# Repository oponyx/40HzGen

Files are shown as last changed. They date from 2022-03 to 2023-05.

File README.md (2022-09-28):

:warning: **warning:This device will flash/strobe the light!  Don't use it next to individuals with epilepsy!** :warning:

:warning: **The research has not been tested and has not been proven to work on humans! Use it at your own risk!** :warning:

#
# 40HzGen
An advanced [ESP8266](https://en.wikipedia.org/wiki/ESP8266) based device used to drive a 40Hz (programmable) flashing led light for brain stimulation and non invasive Alzheimer Gamma Light Therapy.

https://www.webmd.com/brain/what-to-know-about-gamma-brain-waves

http://news.mit.edu/2016/visual-stimulation-treatment-alzheimer-1207

https://picower.mit.edu/innovations-inventions/genus

### Features:
  * Complete configuration and control through web pages
  * Programmable Light On-Time, flickering Frequence and Brightness 
  * WIFI Station and AP mode
#

# Prototype board

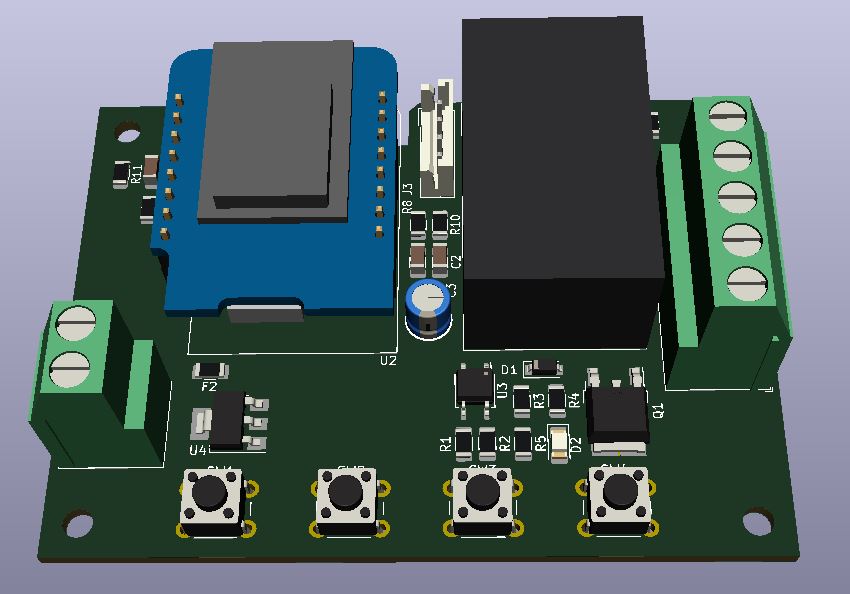
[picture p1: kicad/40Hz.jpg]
Prototype PCB


### Hardware notes:
 * Board designed to be fitted with 'Wemos D1 mini' or 'ESP12F' modules
 * Optional OLED SS1306 Display 
 * Power to logic from AC main (populating PS1 with a HLK-PM01 module) or external 5V
 * External Input for Light Power 
 * ESP01 version (in progress)

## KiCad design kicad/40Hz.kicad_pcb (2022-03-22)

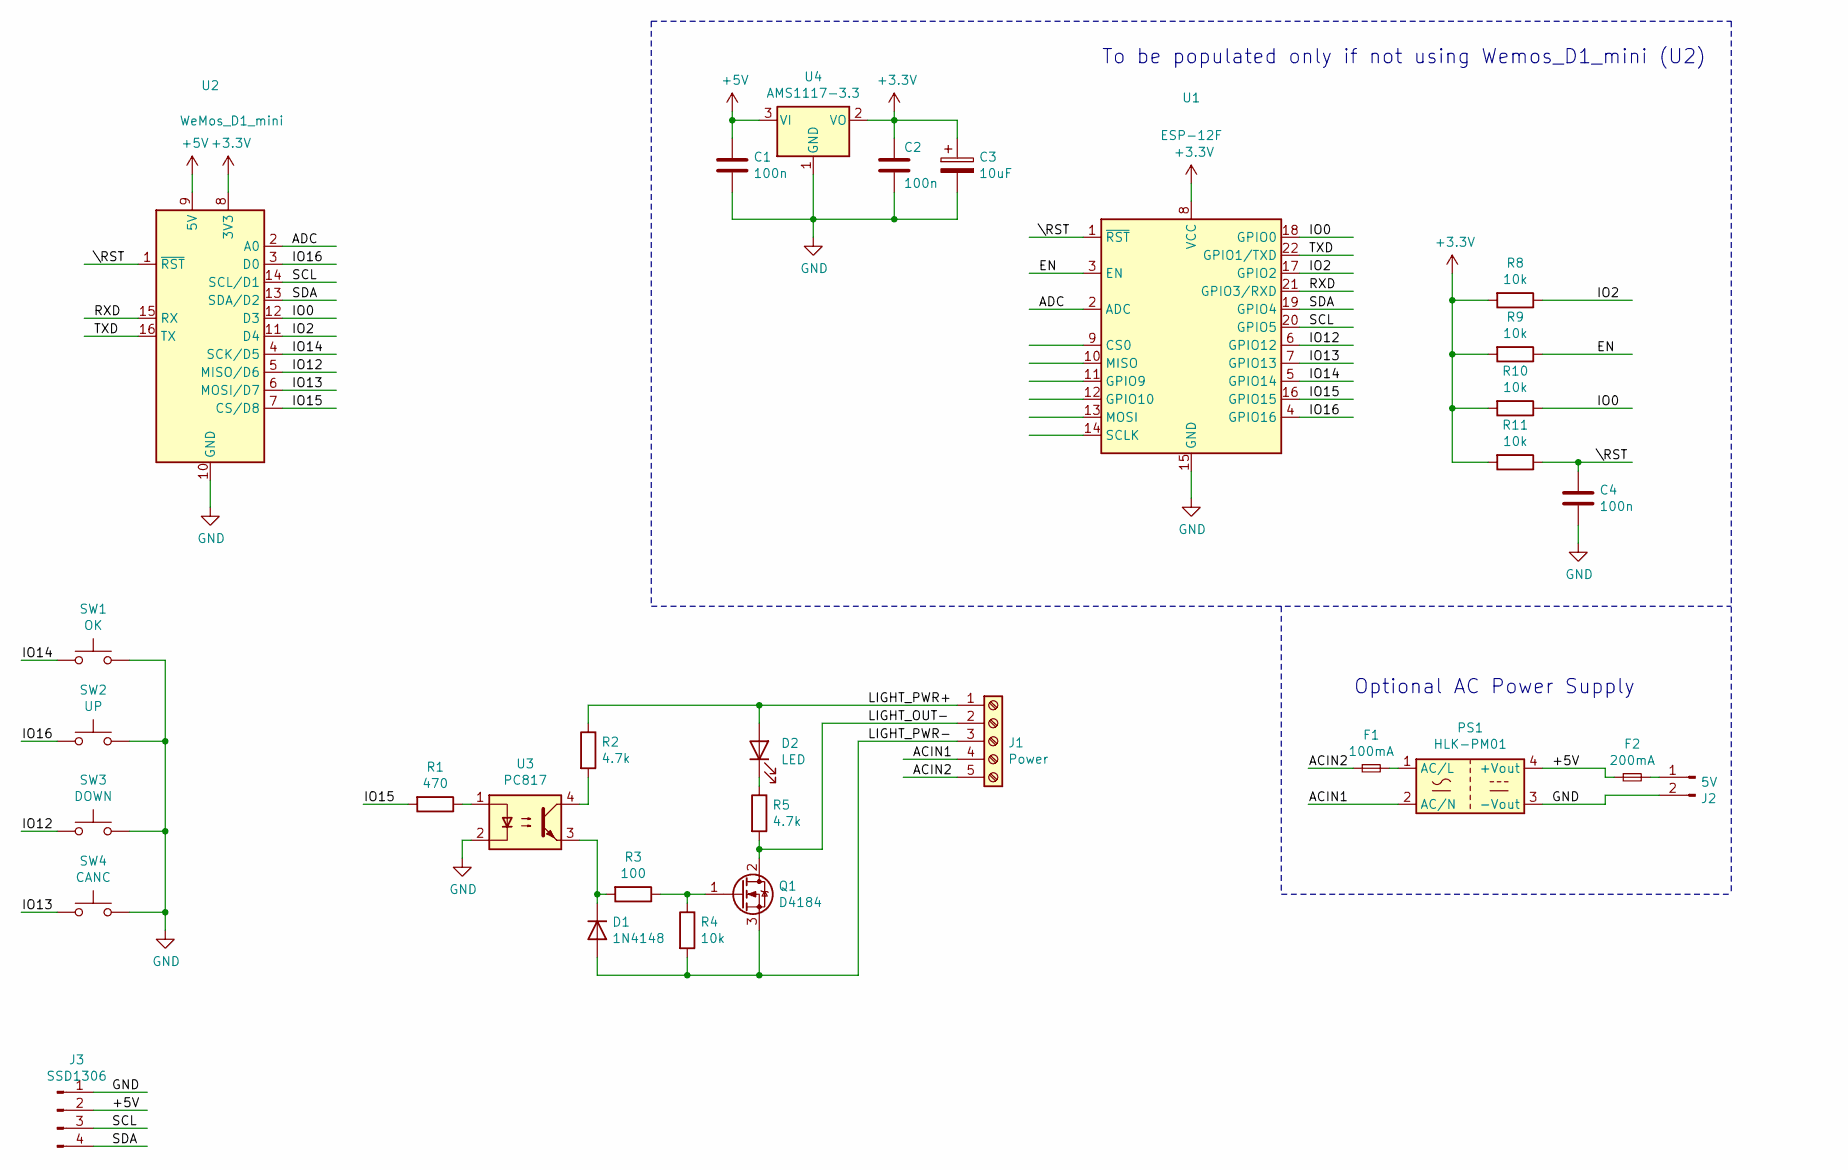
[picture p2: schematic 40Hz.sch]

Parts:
C1, C2, C4: 100n; C_1206_3216Metric
C3: 10uF; CP_Radial_D5.0mm_P2.50mm
D1: 1N4148; D_SOD-123
D2: LED; LED_1206_3216Metric_Pad1.42x1.75mm_HandSolder
F1: 100mA; Fuse_1206_3216Metric
F2: 200mA; Fuse_1206_3216Metric
J1: Power; TerminalBlock_Phoenix_MKDS-3-5-5.08_1x05_P5.08mm_Horizontal
J2: 5V; TerminalBlock_Phoenix_MKDS-3-2-5.08_1x02_P5.08mm_Horizontal
J3: SSD1306; JST_EH_B4B-EH-A_1x04_P2.50mm_Vertical
PS1: HLK-PM01; Converter_ACDC_HiLink_HLK-PMxx
Q1: D4184; TO-252-2
R1: 470; R_1206_3216Metric
R2, R5: 4.7k; R_1206_3216Metric
R3: 100; R_1206_3216Metric
R4, R8, R9, R10, R11: 10k; R_1206_3216Metric
SW1: OK; SW_PUSH_6mm_H5mm
SW2: UP; SW_PUSH_6mm_H5mm
SW3: DOWN; SW_PUSH_6mm_H5mm
SW4: CANC; SW_PUSH_6mm_H5mm
U1: ESP-12F; ESP-12E
U2: WeMos_D1_mini; WEMOS_D1_mini_light
U3: PC817; SOP-4_3.8x4.1mm_P2.54mm
U4: AMS1117-3.3; SOT-223-3_TabPin2

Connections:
+3V3: C2.1, C3.1, R8.2, R9.2, R10.2, R11.2, U1.8 (VCC), U2.8 (3V3), U4.2 (VO)
+5V: C1.1, F2.1, J3.2, PS1.4 (+Vout), U2.9 (5V), U4.3 (VI)
/ACIN1: J1.4, PS1.2 (AC/N)
/ACIN2: F1.1, J1.5
/ADC: U1.2 (ADC), U2.2 (A0)
/EN: R9.1, U1.3 (EN)
/IO0: R10.1, U1.18 (GPIO0), U2.12 (D3)
/IO2: R8.1, U1.17 (GPIO2), U2.11 (D4)
/IO12: SW3.1, U1.6 (GPIO12), U2.5 (MISO/D6)
/IO13: SW4.1, U1.7 (GPIO13), U2.6 (MOSI/D7)
/IO14: SW1.1, U1.5 (GPIO14), U2.4 (SCK/D5)
/IO15: R1.2, U1.16 (GPIO15), U2.7 (CS/D8)
/IO16: SW2.1, U1.4 (GPIO16), U2.3 (D0)
/LIGHT_OUT-: J1.2, Q1.2 (D), R5.2
/LIGHT_PWR+: D2.2 (A), J1.1, R2.1
/LIGHT_PWR-: D1.2 (A), J1.3, Q1.3 (S), R4.2
/RXD: U1.21 (GPIO3/RXD), U2.15 (RX)
/SCL: J3.3, U1.20 (GPIO5), U2.14 (SCL/D1)
/SDA: J3.4, U1.19 (GPIO4), U2.13 (SDA/D2)
/TXD: U1.22 (GPIO1/TXD), U2.16 (TX)
/\RST: C4.1, R11.1, U1.1 (~RST), U2.1 (~RST)
GND: C1.2, C2.2, C3.2, C4.2, J2.2, J3.1, PS1.3 (-Vout), SW1.2, SW2.2, SW3.2, SW4.2, U1.15 (GND), U2.10 (GND), U3.2, U4.1 (GND)
unnamed: D1.1 (K), R3.2, U3.3
unnamed: D2.1 (K), R5.1
unnamed: F1.2, PS1.1 (AC/L)
unnamed: F2.2, J2.1
unnamed: Q1.1 (G), R3.1, R4.1
unnamed: R1.1, U3.1
unnamed: R2.2, U3.4

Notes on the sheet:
To be populated only if not using Wemos_D1_mini (U2)
Optional AC Power Supply

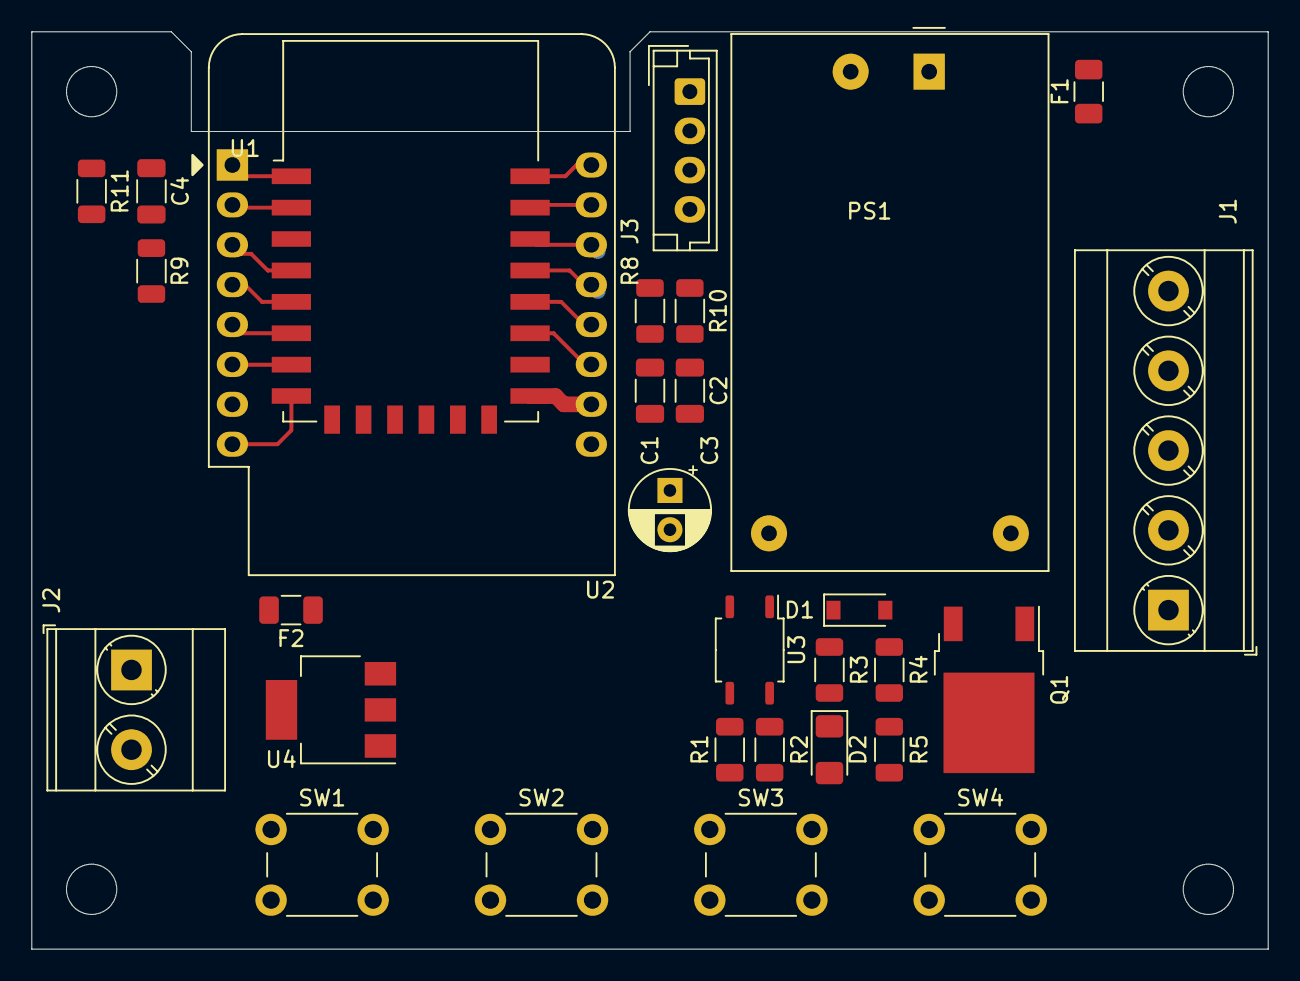
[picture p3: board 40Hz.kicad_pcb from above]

Board: 2 copper layers, 78.7 x 58.4 mm, 30 parts (0 on the bottom side), 29 nets.

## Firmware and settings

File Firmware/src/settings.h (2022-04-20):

/*
settings.h

MIT License

Copyright (c) 2022 Pagliarulo Onofrio (oponyx@hotmail.it)

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
THE SOFTWARE IS PROVIDED "AS IS", WITHOUT WARRANTY OF ANY KIND, EXPRESS OR
IMPLIED, INCLUDING BUT NOT LIMITED TO THE WARRANTIES OF MERCHANTABILITY,
FITNESS FOR A PARTICULAR PURPOSE AND NONINFRINGEMENT. IN NO EVENT SHALL THE
AUTHORS OR COPYRIGHT HOLDERS BE LIABLE FOR ANY CLAIM, DAMAGES OR OTHER
LIABILITY, WHETHER IN AN ACTION OF CONTRACT, TORT OR OTHERWISE, ARISING FROM,
OUT OF OR IN CONNECTION WITH THE SOFTWARE OR THE USE OR OTHER DEALINGS IN THE
SOFTWARE.
*/
#ifndef _SETTINGS_H_
#define _SETTINGS_H_

#include <stdint.h>
#include <EEPROM.h>
#include <CRC16.h>

#define SETTINGS_VERSION          0x00000010

#ifdef WIFI_DEFAULT_ENABLED
#define WIFI_DEFAULT_ENABLED WIFI_DEFAULT_ENABLED_OVERRIDE
#else 
#define WIFI_DEFAULT_ENABLED         true
#endif

#ifdef WIFI_DEFAULT_SSID_OVERRIDE
#define WIFI_DEFAULT_SSID WIFI_DEFAULT_SSID_OVERRIDE
#else 
#define WIFI_DEFAULT_SSID         "SSID_NONE"
#endif

#ifdef WIFI_DEFAULT_PASSW_OVERRIDE
#define WIFI_DEFAULT_PASSW WIFI_DEFAULT_PASSW_OVERRIDE
#else
#define WIFI_DEFAULT_PASSW        "12345678"
#endif

#ifdef AUTOSTART_OVERRIDE
#define AUTOSTART AUTOSTART_OVERRIDE
#else
#define AUTOSTART false
#endif

#define AP_DEFAULT_SSID           "40Hz_Gen"
#define AP_DEFAULT_PASSW          "12345678"
#ifndef DEFAULT_LIGHT_FREQ
#define DEFAULT_LIGHT_FREQ        40
#endif
#ifndef DEFAULT_ON_TIME
#define DEFAULT_ON_TIME           60
#endif
#define DEFAULT_BRIGHTNESS        100
#define DEFAULT_PWM_FREQ          1000
#define DEFAULT_AUDIO_ENABLED     true
#define DEFAULT_LIGHT_ENABLED     true






uint8_t SettingsRead();
uint8_t restoreDefaultSettings();
uint8_t SettingsWrite();
uint16_t SettingsCRC();

typedef union {
  uint8_t data;
  struct {
  uint8_t type            : 3;
  uint8_t autostart       : 1;
  uint8_t spare1          : 1;
  uint8_t wifiEnabled     : 1;
  uint8_t audioEnabled    : 1;
  uint8_t lightEnabled    : 1;
  };
} flags;

typedef struct {
  uint16_t      crc;                        // crc settings
  uint32_t      version;                    // Settings version  
  flags         settingFlags;               // Flag Byte Stored in Settings
  char          wifi_ssid[24];              // Wifi SSID Stored in Setting
  char          wifi_psw[24];               // Wifi Password Stored in Setting
  char          ap_ssid[16];                // Access Poin Mode SSID name Stored in Setting
  char          ap_psw[16];                 // Access Poin Mode Password Stored in Setting
  uint8_t       light_freq;                 // Gamma Frequence Stored in Setting
  uint8_t       on_time;                    // OnTime Stored in Setting
  uint8_t       brightness;                 // light brightness 10-100%
  uint32_t      pwm_freq;                   // light pwm frequence
} TSettings;

extern TSettings Settings;


#endif

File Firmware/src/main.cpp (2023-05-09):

/*
main.cpp - 40HzGen main file

MIT License

Copyright (c) 2022 Pagliarulo Onofrio (oponyx@hotmail.it)

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
THE SOFTWARE IS PROVIDED "AS IS", WITHOUT WARRANTY OF ANY KIND, EXPRESS OR
IMPLIED, INCLUDING BUT NOT LIMITED TO THE WARRANTIES OF MERCHANTABILITY,
FITNESS FOR A PARTICULAR PURPOSE AND NONINFRINGEMENT. IN NO EVENT SHALL THE
AUTHORS OR COPYRIGHT HOLDERS BE LIABLE FOR ANY CLAIM, DAMAGES OR OTHER
LIABILITY, WHETHER IN AN ACTION OF CONTRACT, TORT OR OTHERWISE, ARISING FROM,
OUT OF OR IN CONNECTION WITH THE SOFTWARE OR THE USE OR OTHER DEALINGS IN THE
SOFTWARE.
*/

#include <Arduino.h>

#include "hw_config.h"
#include "config_override.h"
#include "globals.h"
#include "config.h"
#include "log.h"
#include "settings.h"
#include "wifi_func.h"
#include "web_serv.h"
#include "functions.h"
#include "error_codes.h"
#include "button.hpp"
#include "graphic.h"
#include "version.h"



bool bDisplayUpdated;         // 'Display is updated' flag
bool bOutputStatus;
u_long lastSwitch;
bool bButtonChanged=false;
uint16_t LightPWMDutyVal = 0;
deviceStatus_t Status;

Button okButton(OK_BUTTON_PIN, INPUT_PULLUP, OK_BUTT_ACTIVE_LVL);
#ifdef CANCEL_BUTTON_PIN
Button cancelButton(CANCEL_BUTTON_PIN, INPUT_PULLUP, CANCEL_BUTT_ACTIVE_LVL);
#endif
#ifdef UP_BUTTON_PIN
Button upButton(UP_BUTTON_PIN, INPUT_PULLUP, UP_BUTT_ACTIVE_LVL);
#endif
#ifdef DOWN_BUTTON_PIN
Button downButton(DOWN_BUTTON_PIN, INPUT_PULLUP, DOWN_BUTT_ACTIVE_LVL);
#endif


void IRAM_ATTR buttonChangedISR(){
 bButtonChanged = true;
}

/**
 * @brief Main setup function
 * 
 */
void setup() {

#ifdef ESP32
  Serial.begin(115200);
#else
  Serial.begin(74880);
#endif
  // load settings
  D_PRINT(false, "\n");
  D_PRINTLN(true, "Serial ok");
  
  // restore default settings if okButton pressed at powerup
  D_PRINT(true, "Checking if button pressed for reset to default settings...");
  ulong ms = millis();
  while (millis() < (ms + 1000)){
    if(digitalRead(OK_BUTTON_PIN) == OK_BUTT_ACTIVE_LVL){
      D_PRINT(true, "Restoring default settings...");
      restoreDefaultSettings();
    }
  }
  D_PRINTLN(false, "Done");

  D_PRINT(true, "Loading Settings..");
  uint8_t result = SettingsRead();
  if( result != 0 ){
    switch ( result )
    {
    case ERROR_SETTINGS_CRC:
        D_PRINT(true, "\nError: Bad CRC on settings datas\nResoring default settings.\n");
        restoreDefaultSettings();
      break;
    
    default:
      break;
    }
  }else{
    D_PRINT(false, "Ok\n");
  }

#ifdef LCD_POPULATED
  D_PRINT(true, "Setting up Display...");
  if(display_init()){
    D_PRINTLN(false, "FAIL!");
  }
  D_PRINTLN(false, "Ok.");

  dispLogoPage();
  delay(1000);

  display.clearDisplay();
  display.setTextSize(1);             // Normal 1:1 pixel scale
  display.setTextColor(WHITE);        // Draw white text
  display.setCursor(0,0);             // Start at top-left corner

  
  display.printf("Setting up WIFI...");
#endif

  if(Settings.settingFlags.wifiEnabled){
    D_PRINT(true, "Setting up WIFI...");
    if(!wifi_setup()){
      D_PRINTLN(false, "WIFI connection KO!");   
    }
    else{
      D_PRINTLN(false, "OK!");
      D_PRINTLN(true, "WIFI connection Successful");
      D_PRINTLN(true, "WIFI IP Address is:%s", WiFi.localIP().toString().c_str() );
    }
  }
  else{
    D_PRINTLN(true, "Wifi is NOT enabled!!");
  }

  D_PRINT(true, "Setting up AP...");
  if(!AP_setup()){  
    D_PRINTLN(false, "KO!!");
  }
  else{
    D_PRINTLN(false, "OK!");
    D_PRINTLN(true, "AP IP address = %s" ,  WiFi.softAPIP().toString().c_str());
#ifdef LCD_POPULATED
    display.println(WiFi.softAPIP());
#endif
  }

  D_PRINT(true, "Starting web server...");
  if (web_serv_setup() == NO_ERRORS) {
    D_PRINTLN(false, "OK!");
  }else{
    D_PRINTLN(true, "<<<<<<<<<<<<< ERROR!");
  }
  setupIO();
  // test output
#ifdef AUDIO_OUT_PIN
#ifdef ESP32 
  ledcWrite(LIGHT_PWM_CH, (LIGHT_OUT_ACTIVE_LVL)  ? pow(2,LIGHT_PWM_RES_BITS) -1 : 0);
  ledcWriteTone(AUDIO_PWM_CH,1000);
#else
  tone(AUDIO_OUT_PIN,TONE_FREQ);
  //digitalWrite(LIGHT_OUT_PIN,LIGHT_OUT_ACTIVE_LVL); 
#endif
#endif
#ifdef LCD_POPULATED
  dispInfoPage();
#endif
  delay(1000);
#ifdef LCD_POPULATED
  dispReadyPage();
#endif
// test output end
#ifdef ESP32
  ledcWrite(LIGHT_PWM_CH, (LIGHT_OUT_ACTIVE_LVL)  ? 0 : pow(2,LIGHT_PWM_RES_BITS)-1);
  ledcWriteTone(AUDIO_PWM_CH,0);
#else
  digitalWrite(LIGHT_OUT_PIN,!LIGHT_OUT_ACTIVE_LVL); 
  noTone(AUDIO_OUT_PIN);
#endif
  D_PRINTLN(true, "WIFI SSID:%s", Settings.wifi_ssid);
  D_PRINTLN(true, "WIFI PWD:%s", Settings.wifi_psw);
  D_PRINTLN(true, "AP SSID:%s", Settings.ap_ssid);
  D_PRINTLN(true, "AP PWD:%s", Settings.ap_psw);
  D_PRINTLN(true, "Light Freq:%u", Settings.light_freq);
  D_PRINTLN(true, "On time:%u", Settings.on_time);
  D_PRINTLN(true, "Brightness:%u", Settings.brightness);
  D_PRINTLN(true, "PWM Freq:%u", Settings.pwm_freq);
  D_PRINTLN(true, "Autostart:%s", (Settings.settingFlags.autostart == true ) ? "ON" : "OFF");
  D_PRINTLN(true, "lightEnabled:%s", (Settings.settingFlags.lightEnabled == true ) ? "ON" : "OFF");
  D_PRINTLN(true, "audioEnabled:%s", (Settings.settingFlags.audioEnabled == true ) ? "ON" : "OFF");

  attachInterrupt(digitalPinToInterrupt(OK_BUTTON_PIN), buttonChangedISR, CHANGE);

  if(Settings.settingFlags.autostart){
    Command = CMD_START;
  }  
  /// tests
  //check_flash();
  //D_PRINTLN(true, "Size of indexp:%d\n", sizeof(index_page));
  //test();
  //testButtonHandle();
  //system_phy_set_powerup_option(0);  // 3 to reset RF CALIBRATION
}



/**
 * @brief Main Loop
 * 
 */
void loop() {
  if (bButtonChanged) {
    //bButtonChanged = false;
    okButton.handle();// only button handling always checked, other buttons only when not working
  }
  handleCommands();
  if((millis()-mills_2)>499){
    mills_2=millis();
    bHalfSecond=!bHalfSecond;
  }
  //flash status led
#ifdef STATUS_LED
  digitalWrite(STATUS_LED, (bHalfSecond == true) ? STATUS_LED_ACTIVE_LVL : !STATUS_LED_ACTIVE_LVL );   
#endif

  if( Status == deviceStatus_t::STATUS_WORKING ){
    // light switch
    u_long now = micros();
    u_long diff = now - lastSwitch;
    
    if( diff >= semiPeriod ){
      if(Settings.settingFlags.lightEnabled){
#ifdef ESP32
      //(bOutputStatus == false) ? ledcWrite(LIGHT_PWM_CH, (LIGHT_OUT_ACTIVE_LVL)  ? (int)(Settings.brightness) : 100 -(int)(Settings.brightness)) : ledcWrite(LIGHT_PWM_CH, (LIGHT_OUT_ACTIVE_LVL)  ? 0 : 100);
      (bOutputStatus == true) ? ledcWrite(LIGHT_PWM_CH, LightPWMDutyVal) : ledcWrite(LIGHT_PWM_CH, (LIGHT_OUT_ACTIVE_LVL)  ? 0 :pow(2,LIGHT_PWM_RES_BITS)-1);
#else
        (bOutputStatus == true) ? analogWrite(LIGHT_OUT_PIN, (LIGHT_OUT_ACTIVE_LVL)  ? (int)(Settings.brightness) : 100 -(int)(Settings.brightness)) : digitalWrite(LIGHT_OUT_PIN, !LIGHT_OUT_ACTIVE_LVL);
        //if(lightFreqErrorUs > maxLightFreqErrorUs ) maxLightFreqErrorUs = lightFreqErrorUs;
#endif
      }
#ifdef AUDIO_OUT_PIN
      if(Settings.settingFlags.audioEnabled){
#ifdef ESP32
        (bOutputStatus) ? ledcWriteTone(AUDIO_PWM_CH,1000) : ledcWriteTone(AUDIO_PWM_CH,0);
#else
        (bOutputStatus) ? tone(AUDIO_OUT_PIN,TONE_FREQ) : noTone(AUDIO_OUT_PIN);
        //digitalWrite(AUDIO_OUT_PIN, (bOutputStatus) ? bOutputStatus : !bOutputStatus);
#endif
      }
#endif
      lightFreqErrorUs = diff - semiPeriod;  // calculate error
      bOutputStatus = !bOutputStatus;
      lastSwitch = now ; 
    }
    // check for working timeout
    rem_time = (Settings.on_time * 60 - ((millis() - start_millis) / 1000)); // 14 uS
    if(rem_time<=0){
      D_PRINTLN(true, "Timed Out");
      stop();
    }  
  }
  else{ // not working not in menu
      okButton.handle();
#ifdef CANCEL_BUTTON_PIN      
      cancelButton.handle();
#endif      
#ifdef UP_BUTTON_PIN      
      upButton.handle();
#endif      
#ifdef DOWN_BUTTON_PIN      
      downButton.handle();
#endif      
  }  
  if(Status == deviceStatus_t::STATUS_MENU ){
#ifdef LCD_POPULATED
    menu();
#endif
  }
}

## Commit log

2022-02-24 Corrected rebooting page send
    [web_serv.cpp]
2022-02-24 added redirect to rebootin page
    [web_serv.cpp]
2022-02-24 Schematics update
    [40Hz.sch]
2022-02-25 Add CRC Check on Settings
    [40Hz.kicad_pcb, 40Hz.sch]
2022-02-26 Fuse added
    [40Hz.kicad_pcb, 40Hz.sch]
2022-02-26 Schematic update
    [40Hz.sch]
2022-03-03 Button alpha
    [40Hz.kicad_pcb]
2022-03-08 New Buttons, no ISR
2022-09-27 Corrections for env d1_mini (no LCD)
    [functions.cpp, main.cpp]
2023-05-09 Preliminary ESP32 Support
